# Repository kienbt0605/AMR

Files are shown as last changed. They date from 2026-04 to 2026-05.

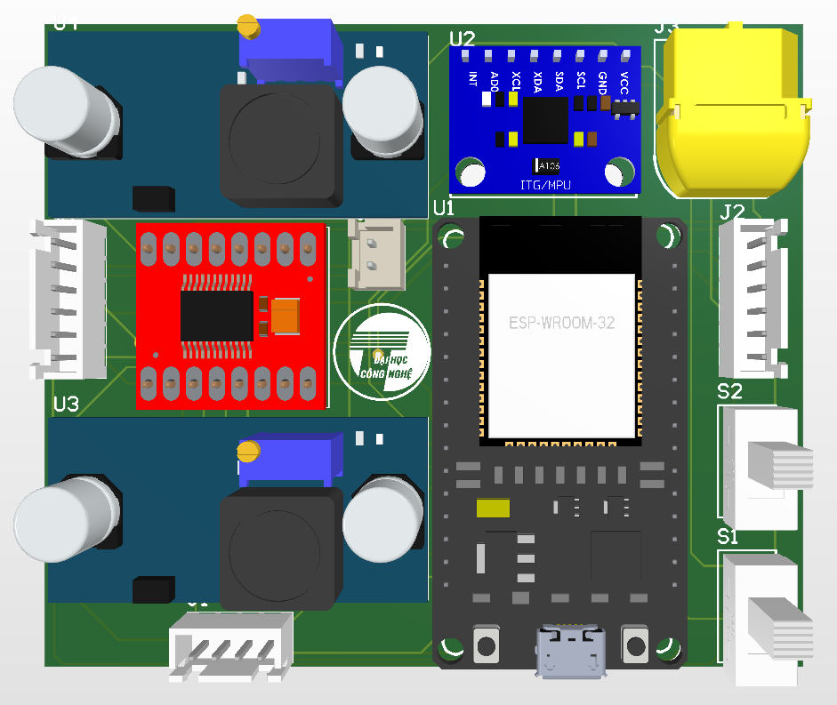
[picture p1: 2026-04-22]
AMR_git/PCB/667359527_941201608501204_695578932031015010_n.png

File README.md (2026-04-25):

⚠️ HEADS UP: THIS IS A WORK-IN-PROGRESS PROJECT, SO NOT ALL FEATURES ARE UP AND RUNNING YET! ⚠️
Autonomous Mobile Robot (AMR) - Navigation & Control
📌 What This Is All About
We're building an Autonomous Mobile Robot (AMR) designed to cruise around indoor spaces on its own. It maps out the room using LiDAR, uses an ESP32 as its main brain, and mixes IMU and encoder data to figure out exactly where it is and how to move. The end goal? Creating a solid, reliable bot for hauling materials around places like smart factories or hospitals.

🚀 Cool Features
Auto-Navigation: Plans out its route using the A* (A-Star) algorithm.

Sensor Fusion: Mashes up data from an MPU6050 (IMU) and incremental encoders for super robust odometry.

Dodging Obstacles: Scans the room in real-time with a 2D LiDAR to avoid bumping into things.

Custom Electronics: We designed our own PCBs to keep the wiring neat and everything running efficiently.

Fast Processing: We cranked up the sampling rate to keep integration errors in its positioning to an absolute minimum.

🛠️ The Hardware Setup
The whole system is built on a layered chassis. Here is the core gear:

The Brain: ESP32 (WROOM-32)

The Senses: * RPLiDAR A1 (for 2D scanning)

MPU6050 (6-Axis IMU)

Optical Encoders (to track speed and distance)

The Muscles: DC Motors with high-torque gearboxes, driven by L298N/DRV8833 boards.

The Juice: 18650 Li-ion Battery Pack hook up with a BMS.

Tracking: MATLAB-based tags to double-check our real-world path against the planned one.

💻 The Software & Math Stuff
1. Motion Control
The bot runs on a nested PID control loop:

Outer Loop: Keeps the heading straight using IMU data.

Inner Loop: Manages the speed of each wheel using feedback from the encoders.

2. Navigation

Pathfinding: Uses the A* algorithm on a grid-style map.

Localization: Calculates odometry using differential drive kinematics, then corrects it using the IMU's heading.

3. Simulation & Testing

MATLAB: We use this to simulate the bot's path and test our control logic against real-world sensor data.

🎮 How to Run It
Want to take it for a spin? Here is how:

Power it up: Turn on the robot and connect your device to the ESP32's WiFi network.

Launch the simulator: Fire up the Odometry_sim.py script on your computer.



Set a destination: Just click anywhere on the simulator screen to make the bot drive there automatically (point-to-point navigation).



⚠️ Bumps in the Road & Fixes
Odometry Drift: We fixed this by tightening up the sampling time. Less gap between updates means less room for errors to stack up.

Sensor Fusion Noise: The IMU and encoders can get a bit noisy, so we wrote specific logic to handle "Straight" vs. "Turning" movements separately to filter the junk data out.

📈 What's Next? (Future Roadmap)
[ ] Add dynamic obstacle avoidance (so it can dodge moving people/objects).

[ ] Hook up SLAM (Simultaneous Localization and Mapping) so it can figure out totally unknown rooms.

[ ] Slap an AI camera on it to recognize objects and handle smart docking.

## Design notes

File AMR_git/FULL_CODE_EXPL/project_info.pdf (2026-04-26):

# AMR Firmware Project

## Tổng quan

Đây là tài liệu và mã nguồn firmware cho dự án Autonomous Mobile Robot (AMR). Hệ thống chịu trách nhiệm điều khiển phần cứng cấp thấp, đọc dữ liệu cảm biến, tính toán vị trí (Odometry) và xử lý giao tiếp (Bluetooth/Wifi).

## Chi tiết luồng hoạt động của cấu trúc mã nguồn

### 1. AMR_MAIN.ino (Luồng thực thi chính)

setup() : Cấu hình phần cứng (I/O, ngắt), cài đặt bộ định thời (Timer Interrupt) để kích hoạt mỗi 20ms. Gọi các hàm khởi tạo của từng module con: IMU_init() , Odom_init() , BT_init() ,

WiFi_init() .
loop() : Vòng lặp liên tục thực hiện các nhiệm vụ:

Gọi IMU_read() để cập nhật góc xoay.
Nếu cờ Timer 20ms ( odomFlag ) bật, gọi Odom_update() để cập nhật tọa độ.
Gọi WiFi_readCommand() để kiểm tra có lệnh mới từ Server (Python) không.
Nếu có lệnh, liên tục gọi hàm goToXY() (bên Odometry.ino ) để điều hướng robot, nếu đến nơi sẽ dừng.
Gửi dữ liệu trạng thái về Python ( WiFi_sendStatus() ) và thiết bị di động qua Bluetooth

( BT_debugAll() ).

### 2. Odometry.ino (Định vị học và Động học)

Odom_update() : Sử dụng số tick thu được từ 2 bánh xe để tính tốc độ ( | ), độ dời ( | )
và góc hướng ( | ) dựa trên mô hình Differential Drive.
velocityToPWM() : Ánh xạ từ vận tốc (mm/s) quy đổi về dải điều chế xung PWM (0-255), xử lý cả các giới hạn quay (dead zone) của motor.
driveVW(v, w) : Chuyển đổi từ vận tốc tổng quát của robot sang vận tốc độc lập cho bánh trái/phải, quy đổi ra PWM rồi đưa cho bộ điều khiển động cơ.
goToXY_init(x, y) : Khởi tạo nhiệm vụ di chuyển: tính tổng quãng đường và góc phải xoay so với vị trí hiện tại.
goToXY(x, y) : Trái tim của việc tự hành, hoạt động qua 2 bước:

Bước 1 (Xoay tại chỗ): Dùng PID_theta() để tự động xoay hướng vào góc mục tiêu. Khi góc hướng (từ IMU) khớp với yêu cầu, nó reset giá trị IMU về 0 và chuyển sang Bước 2.

v, ω | X, Y
Theta

Bước 2 (Đi thẳng): Chạy tới tọa độ yêu cầu. Kết hợp song song 2 bộ điều khiển:

PID_straight() để đồng bộ hóa quãng đường của 2 bánh và PID_heading() để ép hệ
thống đi thành một đường thẳng tuyệt đối. Trả về true khi đã đi đủ quãng đường.

### 3. PID.ino (Thuật toán điều khiển)

PID_theta(setpoint, dt) : Nhận góc sai lệch giữa hướng robot hiện hành và góc cần quay, đưa ra giá trị output (vận tốc góc) để đưa về 0.
PID_heading(dt) : Tính toán lượng sai số góc lệch ( yaw ) khi robot đang đi thẳng, xuất ra đại lượng bù ( correction ) trên PWM giúp robot chỉnh lái ngay khi chệch quỹ đạo thẳng. PID_straight(dt) : So sánh sự chênh lệch số vòng quay (encoder ticks) giữa 2 bánh khi đi thẳng. Trả về giá trị bù cho PWM để bánh chậm sẽ tăng tốc và bánh nhanh sẽ giảm tốc, giúp 2 bánh chạy hoàn toàn bằng nhau.

### 4. IMU.ino (Cảm biến quán tính)

IMU_init() : Khởi tạo I2C kết nối với MPU6050, đo tự động trung bình 1000 mẫu bù trừ độ lệch (calibrate offset) của trục Z lúc robot đứng im.
IMU_read() : Đọc gia tốc quay ( gz ), tích phân liên tục theo khoảng thời gian ( dt ) để ra góc xoay yaw với độ chính xác cao.
IMU_reset() : Thiết lập lại góc yaw về 0 (quan trọng cho giai đoạn robot bắt đầu chạy thẳng Bước 2 để tránh sai số lũy kế).

### 5. Motor.ino & Encoder.ino (Phần cứng I/O)

Motor(LPWM, RPWM) : Dịch các lệnh xung thành trạng thái chốt các chân rơ-le/cầu H (IN1 -> IN4) để xác định chiều quay bánh trái và phải, cấp nguồn điều tốc.
encoder1_isr() , encoder2_isr() : Hàm phục vụ ngắt phần cứng mỗi khi đĩa encoder ghi nhận vòng quay. Xét kênh B để phân tích chiều tiến hoặc lùi, qua đó tăng hoặc giảm biến bộ đếm tương ứng.

### 6. Wifi.ino (Giao tiếp mạng TCP/IP)

WiFi_init() : Phát mạng Access Point độc lập và mở Server port TCP 8080. WiFi_readCommand() : Đọc gói tin gửi tới từ máy tính chạy Python (cú pháp ví dụ:
GO,500.0,300.0 ), phân giải toạ độ | , sau đó gọi goToXY_init() kích hoạt di chuyển.
WiFi_sendStatus() : Đóng gói trạng thái tọa độ hiện tại ( | ) để gửi về cho giao diện
mô phỏng vẽ bản đồ.

### 7. Bluetooth_debug.ino (Gỡ lỗi không dây)

X, Y
X, Y , Y aw

## Tài liệu giải thích code chi tiết (từng dòng)

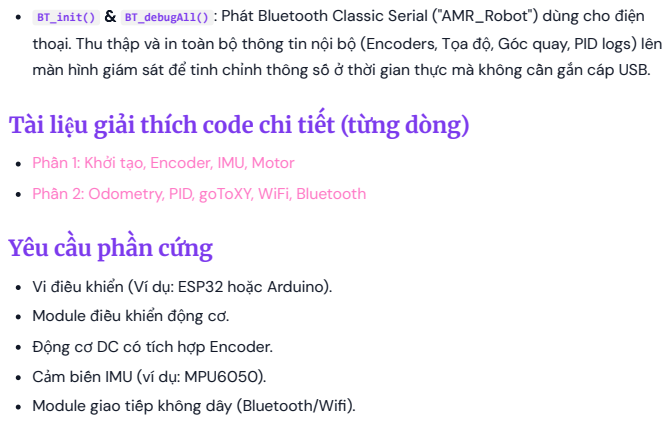
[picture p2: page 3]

BT_init() & BT_debugAll() : Phát Bluetooth Classic Serial ("AMR_Robot") dùng cho điện
thoại. Thu thập và in toàn bộ thông tin nội bộ (Encoders, Tọa độ, Góc quay, PID logs) lên
màn hình giám sát để tinh chỉnh thông số ở thời gian thực mà không cần gắn cáp USB.

Phần 1: Khởi tạo, Encoder, IMU, Motor
Phần 2: Odometry, PID, goToXY, WiFi, Bluetooth
Yêu cầu phần cứng

Vi điều khiển (Ví dụ: ESP32 hoặc Arduino).
Module điều khiển động cơ.
Động cơ DC có tích hợp Encoder.
Cảm biến IMU (ví dụ: MPU6050).
Module giao tiếp không dây (Bluetooth/Wifi).

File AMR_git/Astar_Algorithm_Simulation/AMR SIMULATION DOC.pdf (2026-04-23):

### PHÂN TÍCH CODE MÔ PHỎNG AMR ODOMETRY SIMULATION

### – DIFFERENTIAL DRIVE

Author: KienBui_github.com/kienbt0605

### 1. Giới thiệu

Đoạn chương trình mô phỏng một robot di động tự hành kiểu 2 bánh vi sai (Differential Drive Robot), có khả năng di chuyển từ điểm đầu đến các điểm đích, đồng thời tính toán odometry để cập nhật vị trí và hướng của robot theo thời gian. Ngoài phần điều hướng cơ bản theo waypoint, chương trình còn tích hợp thuật toán A* để tìm đường trên bản đồ lưới có vật cản, kết hợp giao diện trực quan bằng Matplotlib để người dùng tương tác trực tiếp với mô phỏng.

### 2. Mục tiêu của chương trình

Chương trình được xây dựng nhằm phục vụ các mục tiêu chính sau:

- Mô phỏng chuyển động của robot vi sai trong không gian 2D.
- Tính toán quỹ đạo robot bằng phương pháp odometry từ số xung encoder của hai bánh.
- Cho phép robot di chuyển theo các waypoint do người dùng chọn.
- Hỗ trợ tìm đường tránh vật cản bằng thuật toán A* trên occupancy grid.
- Trực quan hóa trạng thái robot, vận tốc, số tick encoder, thời gian và quỹ đạo di chuyển trong thời gian thực.

### 3. Cơ sở lý thuyết

### 3.1. Mô hình robot vi sai

Robot trong chương trình là loại 2 bánh chủ động, với các thông số chính:

- Khoảng cách hai bánh: 205 mm
- Đường kính bánh xe: 66 mm
- Encoder: 495 tick/vòng

Từ đó, chương trình tính:

- Chu vi bánh xe: C = πD
- Quãng đường đi được trên mỗi tick:

với D là đường kính bánh xe và N là số tick trên một vòng quay.

### 3.2. Odometry

Khi biết số tick tăng thêm của bánh trái và bánh phải trong một chu kỳ, chương trình tính:

- Quãng đường bánh trái:
- Quãng đường bánh phải:
- Quãng đường trung bình của robot:
- Góc quay của robot:

Trong đó L là khoảng cách giữa hai bánh. Sau đó robot cập nhật vị trí bằng công thức mid-point approximation:

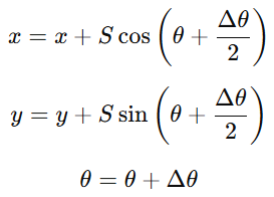
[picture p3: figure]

Ngoài ra, chương trình còn tính vận tốc từng bánh, vận tốc tuyến tính và vận tốc góc từ số tick encoder trong chu kỳ lấy mẫu DT=0.05s

### 4. Cấu trúc chương trình

Chương trình được tổ chức thành các khối chính sau.

### 4.1. Khối khai báo thông số

Phần đầu chương trình định nghĩa toàn bộ các hằng số cho robot, bản đồ và mô phỏng như:

- kích thước robot,
- kích thước bản đồ 2000 × 2000 mm,
- kích thước ô lưới 100 mm,
- tốc độ robot,
- tốc độ quay,
- khoảng cách an toàn với vật cản.

### 4.2. Lớp DifferentialDriveRobot

Đây là lớp cốt lõi mô tả trạng thái vật lý của robot, gồm:

- vị trí x,yx, yx,y,
- góc hướng θ\thetaθ,
- tổng số tick của bánh trái và bánh phải,
- vận tốc bánh trái, bánh phải,
- vận tốc tuyến tính và vận tốc góc,
- lịch sử quỹ đạo di chuyển.

Hàm quan trọng nhất của lớp là compute_odometry(), dùng để cập nhật trạng thái robot dựa trên số tick của hai bánh trong từng bước mô phỏng.

### 4.3. Khối điều hướng point-to-point

Các hàm compute_angle_to_target(), compute_distance_to_target() và normalize_angle() hỗ trợ robot xác định:

- góc cần quay để hướng tới đích,
- khoảng cách đến đích,
- chuẩn hóa góc về miền [−π,π]

### 4.4. Hàm generate_motion_commands()

Hàm này sinh ra chuỗi lệnh chuyển động dưới dạng:

cho từng waypoint.

Nguyên lý hoạt động gồm 3 bước:

1. Tính góc lệch giữa robot và điểm đích.
2. Quay tại chỗ để chỉnh hướng.
3. Đi thẳng đến waypoint.

Điểm đáng chú ý là chương trình không điều khiển robot trực tiếp theo phản hồi liên tục, mà sinh trước toàn bộ chuỗi lệnh encoder rồi phát lại trong mô phỏng. Đây là dạng mô phỏng theo quỹ đạo đặt trước kết hợp cập nhật odometry.

### 4.5. Lớp A* Pathfinder

Lớp này triển khai thuật toán A* để tìm đường ngắn nhất trên lưới chiếm dụng. Một số đặc điểm:

- Hỗ trợ 8 hướng di chuyển.
- Dùng Euclidean distance làm heuristic.
- Có bước inflate_grid() để tạo vùng đệm an toàn quanh vật cản.
- Không cho robot đi chéo xuyên qua góc vật cản.

### 4.6. Lớp OdometrySimulator

Đây là phần giao diện và điều phối mô phỏng. Lớp này đảm nhiệm:

- vẽ bản đồ, robot, waypoint và vật cản,
- hiển thị thông số trạng thái theo thời gian thực,
- xử lý animation,
- xử lý tương tác chuột và các nút điều khiển,
- quản lý A* path, undo, zoom, pan, collision.

### 5. Nguyên lý hoạt động tổng thể

Khi chạy chương trình, hàm main() thực hiện các bước:

1. In thông số robot ra terminal.
2. Tạo robot tại vị trí ban đầu.
3. Sinh chuỗi lệnh di chuyển từ danh sách waypoint.
4. Khởi tạo đối tượng mô phỏng.
5. Chạy animation để hiển thị robot di chuyển.
6. Sau khi kết thúc, in vị trí cuối, hướng cuối, tổng số tick và thời gian di chuyển.

Trong quá trình animation, hàm animate() sẽ lấy từng lệnh trong commands, cộng dồn số tick tương ứng, sau đó gọi compute_odometry() để cập nhật vị trí robot. Nếu phát hiện va chạm thì robot dừng lại và giao diện đổi màu cảnh báo.

### 6. Chức năng tương tác của giao diện

Giao diện mô phỏng cho phép người dùng thao tác trực tiếp bằng chuột và nút bấm:

- Waypoint mode: nhấn chuột để thêm điểm đích.
- Obstacle mode: thêm vật cản hình tròn hoặc hình chữ nhật.
- A* mode: chọn đích để chương trình tự tìm đường tránh vật cản.
- Undo: quay lại hành động trước đó.
- Slider tốc độ: thay đổi tốc độ mô phỏng.
- Zoom / Pan: lăn chuột để phóng to thu nhỏ, giữ chuột phải để kéo bản đồ.

Ngoài ra, giao diện còn hiển thị liên tục:

- Tọa độ x, y
- Góc θ
- Tick encoder trái/phải
- Vận tốc trái/phải
- Vận tốc tuyến tính
- Vận tốc góc
- Thời gian mô phỏng
- Trạng thái hành động hiện tại

### 7. Ưu điểm của chương trình

Thứ nhất, chương trình có cấu trúc khá rõ ràng, tách riêng phần mô hình robot, phần sinh lệnh, phần tìm đường và phần giao diện, nên dễ đọc và dễ mở rộng.

Thứ hai, phần odometry được xây dựng đúng theo mô hình động học cơ bản của robot vi sai, đồng thời có tính thêm vận tốc bánh xe và vận tốc góc nên khá phù hợp cho mục đích học tập, minh họa và kiểm chứng thuật toán.

Thứ ba, chương trình có tính trực quan cao nhờ animation và phần tương tác mạnh, cho phép người dùng tự đặt waypoint, vật cản và kiểm tra đường đi A*.

Thứ tư, việc tích hợp A* với occupancy grid và inflation giúp mô phỏng gần hơn với bài toán điều hướng thực tế trong môi trường có chướng ngại vật.

### 8. Hạn chế của chương trình

Mặc dù chương trình tốt cho mục đích mô phỏng, vẫn còn một số hạn chế.

Thứ nhất, mô hình hiện tại chủ yếu là mô hình động học và odometry, chưa mô phỏng động lực học thật của robot như quán tính, ma sát, trượt bánh hay độ trễ cơ cấu chấp hành. Điều này có thể thấy qua việc trạng thái robot được cập nhật trực tiếp từ tick encoder lý tưởng.

Thứ hai, chuỗi lệnh chuyển động được sinh trước theo waypoint, nên chưa thể hiện rõ bộ điều khiển kín như PID, pure pursuit hay feedback tracking trong thời gian thực.

Thứ ba, mã nguồn chưa có mô hình sai số cảm biến, nhiễu encoder hay drift odometry, trong khi đây là các yếu tố rất quan trọng ở robot thực. Nội dung này không xuất hiện trong phần tính toán hay cập nhật trạng thái của chương trình.

Thứ tư, kiểm tra va chạm hiện tại dùng mô hình hình tròn cho thân robot và hình tròn/hình chữ nhật cho vật cản, nên vẫn còn đơn giản so với hình dạng robot thực.

### 9. Hướng phát triển

Để nâng cấp chương trình, có thể mở rộng theo các hướng sau:

- Bổ sung mô hình nhiễu encoder và sai số odometry.
- Tích hợp bộ điều khiển bám quỹ đạo như PID hoặc Pure Pursuit.
- Thêm cảm biến giả lập như LiDAR, IMU hoặc cảm biến khoảng cách.
- Xây dựng bản đồ phức tạp hơn hoặc đọc map từ file.
- So sánh quỹ đạo thực và quỹ đạo ước lượng để đánh giá sai số.
- Bổ sung nhiều robot để mô phỏng bài toán đa robot.

Những hướng này phù hợp với nền tảng hiện có vì mã nguồn đã tách khá rõ các khối chức năng.

### 10. Kết luận

Tóm lại, chương trình là một mô phỏng khá hoàn chỉnh cho bài toán robot vi sai sử dụng odometry để điều hướng trong môi trường 2D. Điểm mạnh của chương trình nằm ở việc kết hợp giữa lý thuyết odometry, điều hướng theo waypoint, tìm đường A* và giao diện trực quan tương tác tốt. Đây là nền tảng phù hợp để học tập, trình bày đồ án hoặc phát triển tiếp sang các bài toán điều hướng nâng cao hơn trong robot tự hành.

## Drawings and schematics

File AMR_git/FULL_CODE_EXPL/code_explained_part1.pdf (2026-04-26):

# Giải thích chi tiết Code AMR - Phần 1: Khởi tạo & Cảm biến

## Tài liệu giải thích từng dòng code theo đúng thứ tự workflow khi robot khởi động và vận

hành.

# PHASE 1: KHỞI TẠO HỆ THỐNG ( setup() trong AMR_MAIN.ino)

## 1.1 Khai báo thư viện & hằng số

#include <WiFi.h> | // Thư viện WiFi cho ESP32

#include <esp_now.h> | // Giao thức ESP-NOW (dự phòng)

#include <Arduino.h> | // Lõi Arduino

#include <math.h> | // Hàm toán học (sin, cos, atan2, sqrt)

#include <Wire.h> | // Giao tiếp I2C (cho IMU)

#include <MPU6050.h> | // Thư viện cảm biến MPU6050

Thông số vật lý robot:

#define WHEEL_DIAMETER 66.0 | // Đường kính bánh xe = 66mm

#define WHEEL_BASE | 205.0 // Khoảng cách giữa 2 tâm bánh = 205mm

#define ENCODER_PPR | 495.0 // Encoder phát 495 xung mỗi vòng quay bánh

## Các giá trị này là nền tảng cho MỌI phép tính odometry và PID. Sai số ở đây sẽ ảnh

hưởng toàn bộ hệ thống.

Chân điều khiển:

#define IN1 19 | // Chiều quay Motor trái - chân 1

#define IN2 18 | // Chiều quay Motor trái - chân 2

#define IN3 17 | // Chiều quay Motor phải - chân 1

#define IN4 16 | // Chiều quay Motor phải - chân 2

#define ENA 25 | // PWM điều tốc Motor trái

#define ENB 26 | // PWM điều tốc Motor phải

#define STBY 15 // Chân Standby driver (HIGH = bật)

## 1.2 Hàm setup() — Trình tự khởi tạo

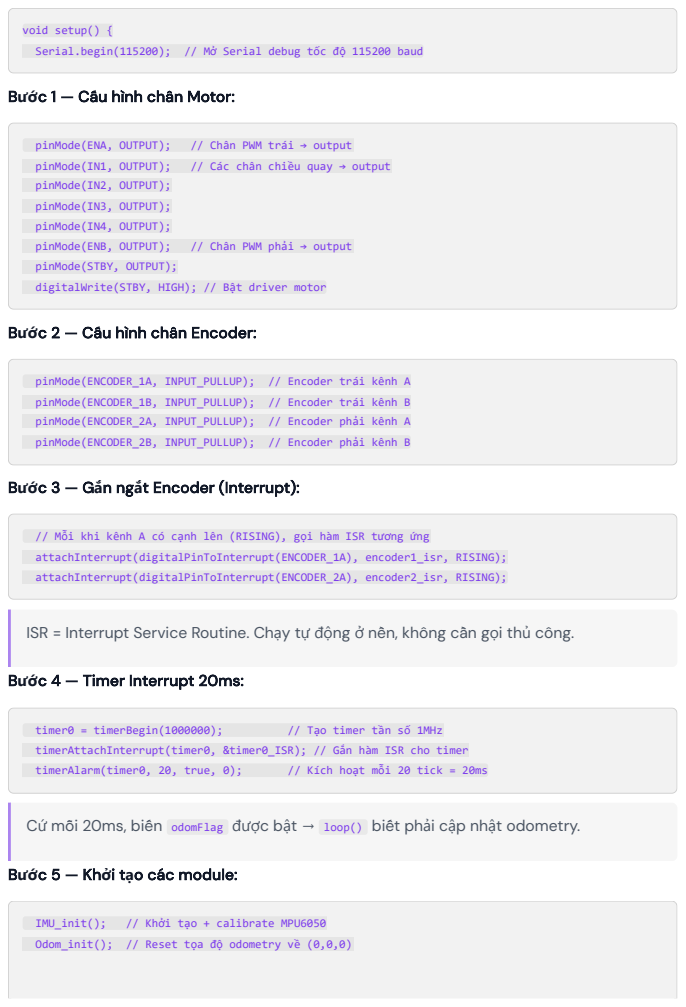
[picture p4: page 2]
pinMode(ENA, OUTPUT);; // Chân PWM trái → output; pinMode(IN1, OUTPUT);; // Các chân chiều quay → output; pinMode(ENB, OUTPUT);; // Chân PWM phải → output; timer0 = timerBegin(1000000);; // Tạo timer tần số 1MHz; timerAlarm(timer0, 20, true, 0);; // Kích hoạt mỗi 20 tick = 20ms; IMU_init();; // Khởi tạo + calibrate MPU6050

void setup() {
Serial.begin(115200); // Mở Serial debug tốc độ 115200 baud

Bước 1 — Cấu hình chân Motor:

pinMode(IN2, OUTPUT);
pinMode(IN3, OUTPUT);
pinMode(IN4, OUTPUT);
pinMode(STBY, OUTPUT);
digitalWrite(STBY, HIGH); // Bật driver motor

Bước 2 — Cấu hình chân Encoder:

pinMode(ENCODER_1A, INPUT_PULLUP); // Encoder trái kênh A
pinMode(ENCODER_1B, INPUT_PULLUP); // Encoder trái kênh B
pinMode(ENCODER_2A, INPUT_PULLUP); // Encoder phải kênh A
pinMode(ENCODER_2B, INPUT_PULLUP); // Encoder phải kênh B

Bước 3 — Gắn ngắt Encoder (Interrupt):

// Mỗi khi kênh A có cạnh lên (RISING), gọi hàm ISR tương ứng
attachInterrupt(digitalPinToInterrupt(ENCODER_1A), encoder1_isr, RISING);
attachInterrupt(digitalPinToInterrupt(ENCODER_2A), encoder2_isr, RISING);

ISR = Interrupt Service Routine. Chạy tự động ở nền, không cần gọi thủ công.

Bước 4 — Timer Interrupt 20ms:

timerAttachInterrupt(timer0, &timer0_ISR); // Gắn hàm ISR cho timer

Cứ mỗi 20ms, biến odomFlag được bật → loop() biết phải cập nhật odometry.

Bước 5 — Khởi tạo các module:

Odom_init(); // Reset tọa độ odometry về (0,0,0)

# PHASE 2: CẢM BIẾN — ENCODER (Encoder.ino)

## 2.1 encoder1_isr() — Ngắt Encoder bánh trái

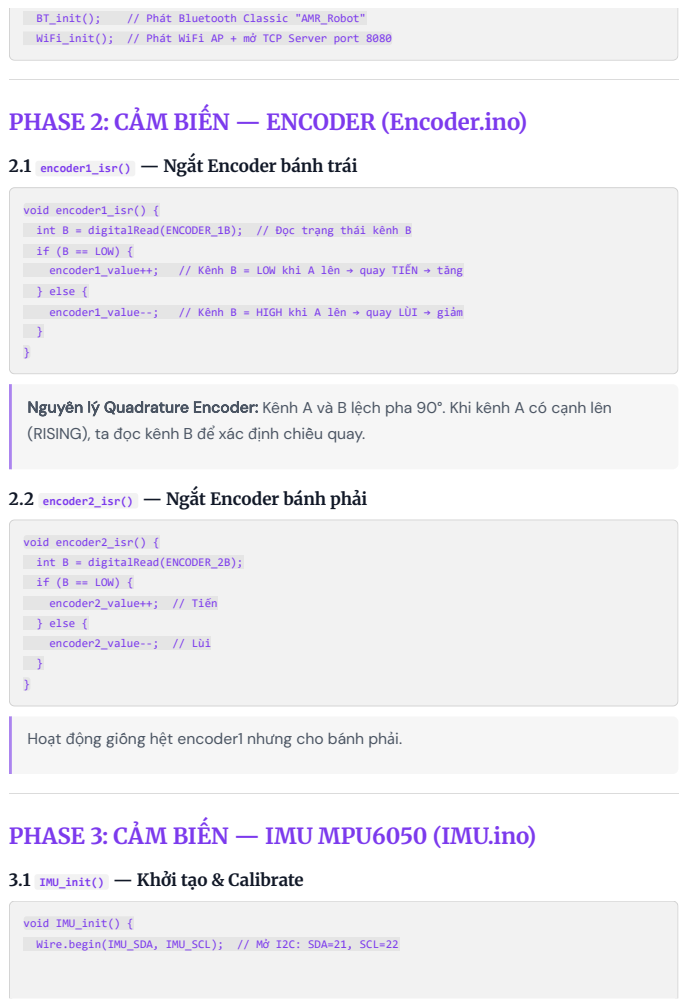
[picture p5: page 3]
BT_init();; // Phát Bluetooth Classic "AMR_Robot"; encoder1_value++;; // Kênh B = LOW khi A lên → quay TIẾN → tăng; encoder1_value--;; // Kênh B = HIGH khi A lên → quay LÙI → giảm; void encoder2_isr() {; int B = digitalRead(ENCODER_2B); if (B == LOW) {; encoder2_value++; // Tiến; } else { encoder2_value--; // Lùi

WiFi_init(); // Phát WiFi AP + mở TCP Server port 8080

void encoder1_isr() {
int B = digitalRead(ENCODER_1B); // Đọc trạng thái kênh B
if (B == LOW) {
} else {

Nguyên lý Quadrature Encoder: Kênh A và B lệch pha 90°. Khi kênh A có cạnh lên
(RISING), ta đọc kênh B để xác định chiều quay.

2.2 encoder2_isr() — Ngắt Encoder bánh phải

Hoạt động giống hệt encoder1 nhưng cho bánh phải.

PHASE 3: CẢM BIẾN — IMU MPU6050 (IMU.ino)

3.1 IMU_init() — Khởi tạo & Calibrate

void IMU_init() {
Wire.begin(IMU_SDA, IMU_SCL); // Mở I2C: SDA=21, SCL=22

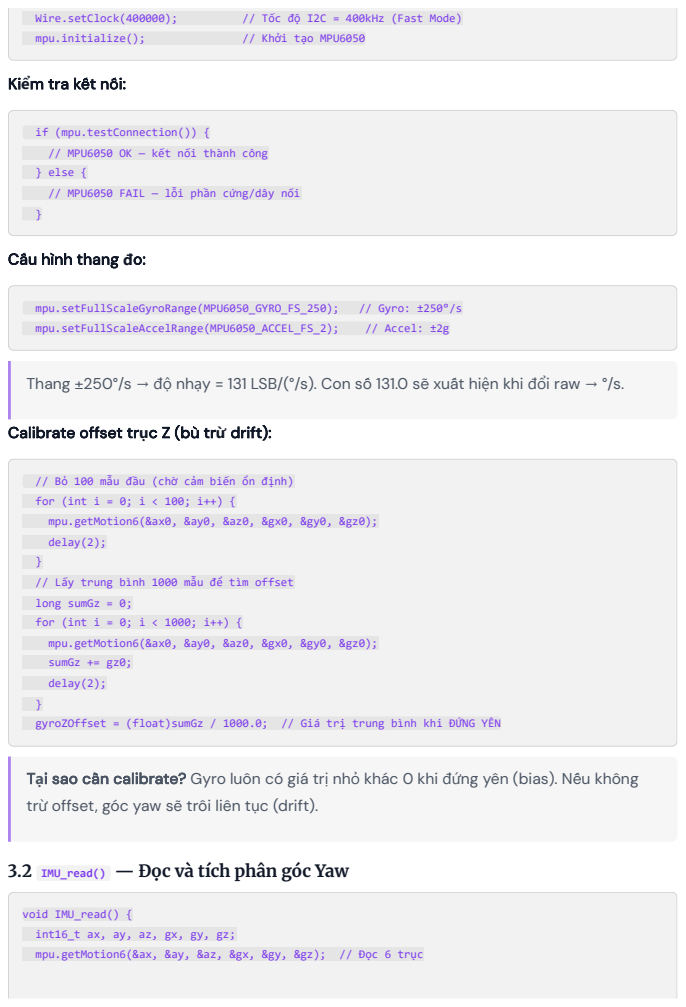
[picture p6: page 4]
Wire.setClock(400000);; // Tốc độ I2C = 400kHz (Fast Mode); mpu.initialize();; // Khởi tạo MPU6050; mpu.setFullScaleGyroRange(MPU6050_GYRO_FS_250);; // Gyro: ±250°/s; mpu.setFullScaleAccelRange(MPU6050_ACCEL_FS_2);; // Accel: ±2g

Kiểm tra kết nối:

if (mpu.testConnection()) {
// MPU6050 OK — kết nối thành công
} else {
// MPU6050 FAIL — lỗi phần cứng/dây nối

Cấu hình thang đo:

Thang ±250°/s → độ nhạy = 131 LSB/(°/s). Con số 131.0 sẽ xuất hiện khi đổi raw → °/s.

Calibrate offset trục Z (bù trừ drift):
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

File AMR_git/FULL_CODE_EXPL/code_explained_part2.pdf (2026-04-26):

# Giải thích chi tiết Code AMR - Phần 2: Odometry, PID, WiFi, Bluetooth

Tiếp nối Phần 1. Đây là phần lõi thuật toán điều khiển.

# PHASE 5: ODOMETRY — Tính toán vị trí (Odometry.ino)

## 5.1 Hằng số tính toán

const float WHEEL_CIRCUMFERENCE = PI * WHEEL_DIAMETER;
// = 3.14159 × 66.0 = 207.35mm (chu vi bánh xe)

const float DISTANCE_PER_TICK = WHEEL_CIRCUMFERENCE / ENCODER_PPR; // = 207.35 / 495 = 0.4188mm (quãng đường mỗi tick encoder)

## 5.2 Odom_init() — Reset về gốc tọa độ

void Odom_init() {
odom_x = 0.0; | // Vị trí X = 0mm
odom_y = 0.0; | // Vị trí Y = 0mm
odom_theta = 0.0; // Góc hướng = 0 rad
prev_encoder1 = encoder1_value; // Lưu giá trị encoder hiện tại prev_encoder2 = encoder2_value; // làm mốc ban đầu
odom_prevTime = micros(); | // Lưu thời điểm hiện tại
}

## 5.3 Odom_update() — Cập nhật tọa độ (gọi mỗi 20ms)

Tính thời gian trôi qua:

void Odom_update() {
unsigned long now = micros();
float dt = (now - odom_prevTime) / 1000000.0; // Microseconds → Seconds odom_prevTime = now;
if (dt <= 0 || dt > 1.0) dt = 0.02; // Bảo vệ: nếu bất thường → dùng 20ms

Tính delta ticks (số xung thay đổi):

int delta_tickL = (encoder1_value - prev_encoder1); // Xung mới - xung cũ trái int delta_tickR = (encoder2_value - prev_encoder2); // Xung mới - xung cũ phải prev_encoder1 = encoder1_value; // Cập nhật mốc cho lần sau prev_encoder2 = encoder2_value;

Tính vận tốc từng bánh:

// v = (delta_tick × π × D) / (N × dt)
vLeft = (delta_tickL * PI * WHEEL_DIAMETER) / (ENCODER_PPR * dt);
vRight = (delta_tickR * PI * WHEEL_DIAMETER) / (ENCODER_PPR * dt);
// Ví dụ: 10 ticks trong 0.02s → vLeft = (10 × 3.14 × 66) / (495 × 0.02) = 209 mm/s

v = (vLeft + vRight) / 2.0; // Vận tốc tịnh tiến (mm/s)
w = (vLeft - vRight) / WHEEL_BASE; // Vận tốc góc (rad/s)

Tính quãng đường & cập nhật tọa độ:

float SL = delta_tickL * DISTANCE_PER_TICK; // Quãng đường bánh trái (mm) float SR = delta_tickR * DISTANCE_PER_TICK; // Quãng đường bánh phải (mm)
float S = (SL + SR) / 2.0; | // Quãng đường trung bình
float delta_theta = (SL - SR) / WHEEL_BASE; // Thay đổi góc (rad)

// Mid-point approximation: dùng góc giữa để tính X, Y chính xác hơn odom_x += S * cos(odom_theta + delta_theta / 2.0);
odom_y += S * sin(odom_theta + delta_theta / 2.0);
odom_theta += delta_theta;

x_cood = -odom_x; // Đảo dấu cho phù hợp hệ tọa độ giao diện
y_cood = -odom_y;

odom_theta = atan2(sin(odom_theta), cos(odom_theta)); // Chuẩn hóa [-π, π] }

## 5.4 velocityToPWM() — Chuyển mm/s → PWM

const float MAX_VELOCITY = 594.0; // Đo thực tế: 594 mm/s tại PWM 255
const int MIN_PWM = 50; | // PWM tối thiểu để motor quay được

int velocityToPWM(float velocity_mms) {
if (fabs(velocity_mms) < 5.0) return 0; // Gần 0 → tắt motor

int pwm = (int)(velocity_mms * 255.0 / MAX_VELOCITY);
// Ví dụ: 200 mm/s → pwm = 200 × 255 / 594 = 85

// Đảm bảo PWM >= MIN_PWM khi có lệnh chạy (tránh dead zone motor) if (pwm > 0 && pwm < MIN_PWM) pwm = MIN_PWM;
if (pwm < 0 && pwm > -MIN_PWM) pwm = -MIN_PWM;

## 5.5 driveVW(v, w) — Điều khiển bằng (v, ω)

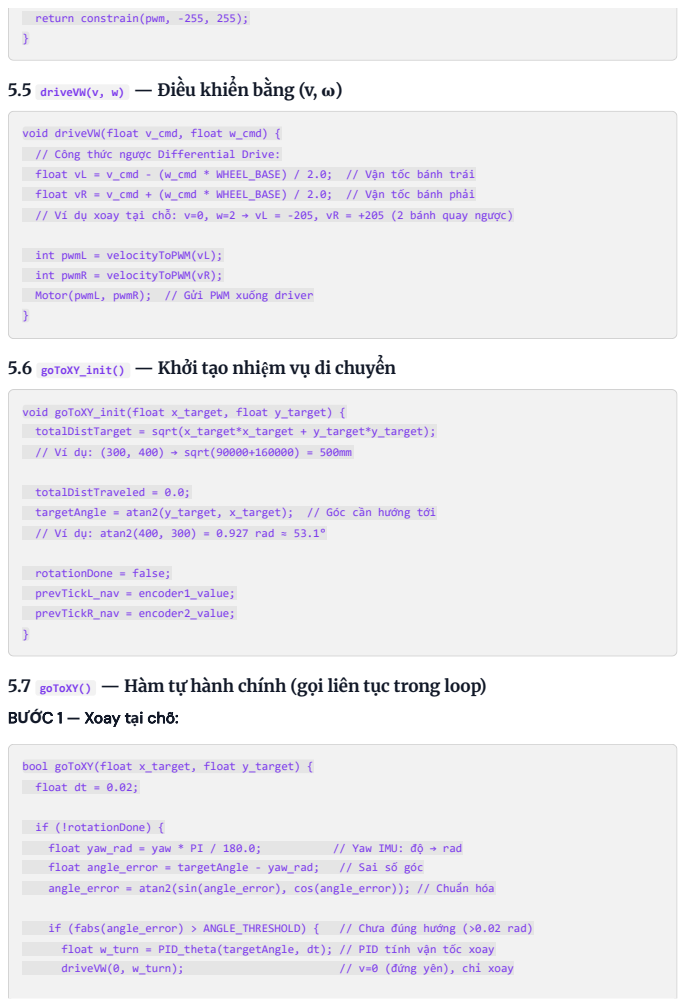
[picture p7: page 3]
rotationDone = false; prevTickL_nav = encoder1_value;; prevTickR_nav = encoder2_value;; float yaw_rad = yaw * PI / 180.0;; // Yaw IMU: độ → rad; float angle_error = targetAngle - yaw_rad;; // Sai số góc; if (fabs(angle_error) > ANGLE_THRESHOLD) {; // Chưa đúng hướng (>0.02 rad); driveVW(0, w_turn);; // v=0 (đứng yên), chỉ xoay

return constrain(pwm, -255, 255);

void driveVW(float v_cmd, float w_cmd) {
// Công thức ngược Differential Drive:
float vL = v_cmd - (w_cmd * WHEEL_BASE) / 2.0; // Vận tốc bánh trái
float vR = v_cmd + (w_cmd * WHEEL_BASE) / 2.0; // Vận tốc bánh phải
// Ví dụ xoay tại chỗ: v=0, w=2 → vL = -205, vR = +205 (2 bánh quay ngược)

int pwmL = velocityToPWM(vL);
int pwmR = velocityToPWM(vR);
Motor(pwmL, pwmR); // Gửi PWM xuống driver

5.6 goToXY_init() — Khởi tạo nhiệm vụ di chuyển

void goToXY_init(float x_target, float y_target) {
totalDistTarget = sqrt(x_target*x_target + y_target*y_target);
// Ví dụ: (300, 400) → sqrt(90000+160000) = 500mm

totalDistTraveled = 0.0;
targetAngle = atan2(y_target, x_target); // Góc cần hướng tới
// Ví dụ: atan2(400, 300) = 0.927 rad ≈ 53.1°

5.7 goToXY() — Hàm tự hành chính (gọi liên tục trong loop)

BƯỚC 1 — Xoay tại chỗ:

bool goToXY(float x_target, float y_target) {
float dt = 0.02;

if (!rotationDone) {
angle_error = atan2(sin(angle_error), cos(angle_error)); // Chuẩn hóa

float w_turn = PID_theta(targetAngle, dt); // PID tính vận tốc xoay
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

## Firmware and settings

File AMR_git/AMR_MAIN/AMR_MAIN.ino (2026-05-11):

#include <WiFi.h>
#include <esp_now.h>
#include <Arduino.h>
#include <math.h>
#include <Wire.h>
#include <MPU6050.h>

#define IMU_SDA 21
#define IMU_SCL 22

// Thông số robot
#define WHEEL_DIAMETER  66.0    // Đường kính bánh xe (mm)        
#define WHEEL_BASE      205.0  // Khoảng cách giữa 2 bánh (mm)   
#define ENCODER_PPR     495.0   // Số xung encoder mỗi vòng quay 

#define IN1 19
#define IN2 18
#define IN3 14
#define IN4 27
#define ENA 25
#define ENB 26 
#define STBY 15 

//Encoder
#define ENCODER_1A 34 // Pin for Encoder A
#define ENCODER_1B 35 // Pin for Encoder B

#define ENCODER_2A 33 // Pin for Encoder A
#define ENCODER_2B 32 // Pin for Encoder B

#define PI  3.141592653589

volatile bool odomFlag = false;
unsigned long startTime = 0;
bool timerStarted = false;
unsigned long goToXY_prevTime = 0;  // Để tính dt thực cho PID trong goToXY

volatile int encoder1_value = 0;
volatile int encoder2_value = 0;
volatile float vRight;
volatile float vLeft;
volatile float v;
volatile float w;

// Extern: biến từ Wifi.ino (compile sau theo alphabet)
extern float wifi_targetX;
extern float wifi_targetY;
extern bool  wifi_hasTarget;

hw_timer_t *timer0 = NULL;
void IRAM_ATTR timer0_ISR() {
  odomFlag = true;
}

void setup() {
  Serial.begin(115200);

  pinMode(ENA, OUTPUT);
  pinMode(IN1, OUTPUT);
  pinMode(IN2, OUTPUT);
  pinMode(IN3, OUTPUT);
  pinMode(IN4, OUTPUT);
  pinMode(ENB, OUTPUT);
  pinMode(STBY, OUTPUT);
  digitalWrite(STBY, HIGH);

  pinMode(ENCODER_1A, INPUT_PULLUP);
  pinMode(ENCODER_1B, INPUT_PULLUP);

  pinMode(ENCODER_2A, INPUT_PULLUP);
  pinMode(ENCODER_2B, INPUT_PULLUP);

  // Attaching the ISR to encoder 1A
  attachInterrupt(digitalPinToInterrupt(ENCODER_1A), encoder1_isr, RISING); 

  // Attaching the ISR to encoder 2A
  attachInterrupt(digitalPinToInterrupt(ENCODER_2A), encoder2_isr, RISING);

  timer0 = timerBegin(1000000);
  // Gắn ISR
  timerAttachInterrupt(timer0, &timer0_ISR);

  // Set alarm sau 1 giây (1,000,000 microseconds)
  timerAlarm(timer0, 20, true, 0); //20ms

  // Khởi tạo MPU6050
  IMU_init();

  // Khởi tạo Odometry
  Odom_init();

  // Khởi tạo WiFi AP + TCP Server
  WiFi_init();
  
  // Bật driver motor
  digitalWrite(STBY, HIGH);

  // Không goToXY_init ở đây — chờ lệnh từ Python qua WiFi
}

bool arrived = true;  // Bắt đầu ở trạng thái đã dừng, chờ lệnh

void loop() {
  // Đọc lệnh từ Python qua WiFi (GO,X,Y) — không cần đồng bộ chặt
  WiFi_readCommand();

  // Tất cả xử lý cần đồng bộ 20ms → đặt trong odomFlag
  if (odomFlag) {
    odomFlag = false;

    // Đọc và cập nhật góc từ MPU6050 (đồng bộ với Odometry)
    IMU_read();

    // Cập nhật Odometry
    Odom_update();

    // Di chuyển đến mục tiêu (nếu có)
    if (!arrived && wifi_hasTarget) {
      // Tính dt thực cho PID (không hardcode 0.02)
      unsigned long now_us = micros();
      float dt_real = (now_us - goToXY_prevTime) / 1000000.0f;
      if (dt_real <= 0 || dt_real > 0.1f) dt_real = 0.02f;  // Bảo vệ
      goToXY_prevTime = now_us;

      arrived = goToXY(wifi_targetX, wifi_targetY, dt_real);
      if (arrived) {
        wifi_hasTarget = false;
      }
    }

    // Gửi trạng thái robot qua WiFi cho Python
    WiFi_sendStatus();

    // In v, w, x, y, theta
    Odom_print();
    IMU_print();

  }
}

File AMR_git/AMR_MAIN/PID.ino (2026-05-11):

// ==================== PID CONTROLLER ====================
// 1. PID Xoay góc: setpoint = odom_theta, actual = yaw (IMU)
// 2. PID Giữ hướng 0° khi đi thẳng: setpoint = 0, actual = yaw (IMU)
// 3. PID Đi thẳng (encoder balance): setpoint = 0, actual = enc1 - enc2
// 4. PID Cross-track: setpoint = 0, actual = lệch ngang (mm)
// ========================================================

// ---- PID Xoay góc (theta) ----
// Dùng khi xoay tại chỗ để hướng về mục tiêu (Bước 1)
float pidTheta_Kp = 2;
float pidTheta_Ki = 0.0;
float pidTheta_Kd = 0.2;  //Damping: giảm overshoot khi xoay

float pidTheta_prevError = 0.0;
float pidTheta_integral  = 0.0;

// ---- PID Giữ hướng 0° khi đi thẳng (heading) ----
// Dùng khi đi thẳng để giữ yaw = 0 (Bước 2)
// Error tính bằng rad (nhỏ, ~0.01-0.1), Kp phải lớn để output ra PWM correction
// Ví dụ: lệch 3° ≈ 0.05 rad → correction = 500 * 0.05 = 25 PWM
float pidHeading_Kp = 5.0;
float pidHeading_Ki = 0.0;
float pidHeading_Kd = 0.0;

float pidHeading_prevError = 0.0;
float pidHeading_integral  = 0.0;

// ---- PID Đi thẳng (encoder balance) ----
float pidStraight_Kp = 5.0;
float pidStraight_Ki = 0.0;
float pidStraight_Kd = 0.0;

float pidStraight_prevError = 0.0;
float pidStraight_integral  = 0.0;

// Giới hạn tích phân (chống windup)
const float INTEGRAL_LIMIT = 100.0;

// Encoder tích lũy khi bắt đầu đi thẳng
int straightStartEnc1 = 0;
int straightStartEnc2 = 0;

// =====================================================
// Reset PID - gọi khi chuyển trạng thái
// =====================================================
void PID_resetTheta()
{
  pidTheta_prevError = 0.0;
  pidTheta_integral  = 0.0;
}

void PID_resetHeading()
{
  pidHeading_prevError = 0.0;
  pidHeading_integral  = 0.0;
}

void PID_resetStraight()
{
  pidStraight_prevError = 0.0;
  pidStraight_integral  = 0.0;
  straightStartEnc1 = encoder1_value;
  straightStartEnc2 = encoder2_value;
}

// =====================================================
// PID Xoay góc
//
// setpoint: targetAngle (góc mục tiêu, rad)
// actual:   yaw từ IMU (chuyển sang rad)
//
// Trả về: w (rad/s) để truyền vào driveVW()
// Dùng cho: Bước 1 - xoay tại chỗ
// =====================================================
float PID_theta(float setpoint_rad, float dt)
{
  // Chuyển yaw IMU từ độ sang rad
  float actual_rad = (float)yaw * PI / 180.0;

  // Tính sai số góc (chuẩn hoá [-PI, PI])
  float error = setpoint_rad - actual_rad;
  error = atan2(sin(error), cos(error));

  // Tích phân
  pidTheta_integral += error * dt;
  pidTheta_integral = constrain(pidTheta_integral, -INTEGRAL_LIMIT, INTEGRAL_LIMIT);

  // Đạo hàm
  float derivative = 0.0;
  if (dt > 0) derivative = (error - pidTheta_prevError) / dt;
  pidTheta_prevError = error;

  // Output PID
  float output = pidTheta_Kp * error 
               + pidTheta_Ki * pidTheta_integral 
               + pidTheta_Kd * derivative;

  // Giới hạn output (rad/s)
  output = constrain(output, -3.0, 3.0);

  return output;
}

// =====================================================
// PID Giữ hướng khi đi thẳng
//
// setpoint: heading_setpoint_deg (góc tuyệt đối cần giữ, đơn vị °)
// actual:   yaw từ IMU (°)
//
// Trả về: correction PWM để kết hợp với PID encoder
// Dùng cho: Bước 2 - đi thẳng, giữ hướng không lệch
// =====================================================
float PID_heading(float setpoint_deg, float dt)
{
  // Sai số góc (°), chuẩn hoá [-180, 180]
  float error = setpoint_deg - yaw;
  // Chuẩn hoá error về [-180, 180]
  while (error > 180.0)  error -= 360.0;
  while (error < -180.0) error += 360.0;

  // Tích phân
  pidHeading_integral += error * dt;
  pidHeading_integral = constrain(pidHeading_integral, -INTEGRAL_LIMIT, INTEGRAL_LIMIT);

  // Đạo hàm
  float derivative = 0.0;
  if (dt > 0) derivative = (error - pidHeading_prevError) / dt;
  pidHeading_prevError = error;

  // Output PID
  float output = pidHeading_Kp * error 
               + pidHeading_Ki * pidHeading_integral 
               + pidHeading_Kd * derivative;

  // Giới hạn output (PWM correction)
  output = constrain(output, -100.0, 100.0);

  return output;
}

// =====================================================
// PID Đi thẳng
//
// setpoint: 0 (2 bánh phải đi bằng nhau)
// actual:   (encoder1 - encoder2) tích lũy từ lúc bắt đầu đi thẳng
//           Nếu > 0: bánh trái đi nhiều hơn → lệch phải
//           Nếu < 0: bánh phải đi nhiều hơn → lệch trái
//
// Trả về: correction để bù vào PWM
//         Motor(basePWM + correction, basePWM - correction)
// =====================================================
float PID_straight(float dt)
{
  // Tính delta encoder từ lúc bắt đầu đi thẳng
  int encL = encoder1_value - straightStartEnc1;
  int encR = encoder2_value - straightStartEnc2;

  // Sai số = hiệu 2 encoder (setpoint = 0)
  float error = (float)(encL - encR);

  // Tích phân
  pidStraight_integral += error * dt;
  pidStraight_integral = constrain(pidStraight_integral, -INTEGRAL_LIMIT, INTEGRAL_LIMIT);

  // Đạo hàm
  float derivative = 0.0;
  if (dt > 0) derivative = (error - pidStraight_prevError) / dt;
  pidStraight_prevError = error;

  // Output PID
  float output = pidStraight_Kp * error 
               + pidStraight_Ki * pidStraight_integral 
               + pidStraight_Kd * derivative;

  // Giới hạn correction
  output = constrain(output, -100.0, 100.0);

  return output;
}

// =====================================================
// PID Cross-track Error (lệch ngang)
//
// setpoint: 0 (robot phải nằm trên đường thẳng lý tưởng)
// actual:   crossTrackError (mm) — tích lũy lệch ngang
//           > 0: lệch trái → cần lái phải
//           < 0: lệch phải → cần lái trái
//
// Bổ sung cho Heading PID:
//   - Heading PID: sửa HƯỚNG (yaw = 0)
//   - Cross-track PID: sửa VỊ TRÍ (kéo robot về đường thẳng)
//
// Trả về: correction PWM
// =====================================================

// Tham số PID cross-track (bắt đầu nhỏ, tăng dần khi tune)
float pidCross_Kp = 10;   // mm → PWM (lệch 10mm → corr 5 PWM)
float pidCross_Ki = 0.0;
float pidCross_Kd = 0.1;

float pidCross_prevError = 0.0;
float pidCross_integral  = 0.0;

void PID_resetCross()
{
  pidCross_prevError = 0.0;
  pidCross_integral  = 0.0;
}

float PID_crossTrack(float error_mm, float dt)
{
  // Tích phân
  pidCross_integral += error_mm * dt;
  pidCross_integral = constrain(pidCross_integral, -INTEGRAL_LIMIT, INTEGRAL_LIMIT);

  // Đạo hàm
  float derivative = 0.0;
  if (dt > 0) derivative = (error_mm - pidCross_prevError) / dt;
  pidCross_prevError = error_mm;

  // Output PID
  float output = pidCross_Kp * error_mm
               + pidCross_Ki * pidCross_integral
               + pidCross_Kd * derivative;

  // Giới hạn correction (nhỏ hơn heading/encoder vì là bổ trợ)
  output = constrain(output, -80.0, 80.0);

  return output;
}

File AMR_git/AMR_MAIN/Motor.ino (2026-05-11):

// ★ Debug: lưu PWM gần nhất để gửi qua telemetry
int lastPWM_L = 0;
int lastPWM_R = 0;

void Motor(int LPWM, int RPWM) 
{
  digitalWrite(STBY, 1);
  LPWM = constrain(LPWM, -255, 255);
  RPWM = constrain(RPWM, -255, 255);

  // ★ Lưu lại để telemetry đọc
  lastPWM_L = LPWM;
  lastPWM_R = RPWM;

  if (LPWM >= 0) 
  {
    digitalWrite(IN1, HIGH);
    digitalWrite(IN2, LOW);
  } 
  else 
  {
    digitalWrite(IN1, LOW);
    digitalWrite(IN2, HIGH);
  }

  // ★ ĐẢO CHIỀU motor phải — sửa lỗi CW không xoay
  if (RPWM >= 0) 
  {
    digitalWrite(IN3, HIGH);
    digitalWrite(IN4, LOW);
  } 
  else 
  {
    digitalWrite(IN3, LOW);
    digitalWrite(IN4, HIGH);
  }

  analogWrite(ENA, abs(LPWM));
  analogWrite(ENB, abs(RPWM));
}
